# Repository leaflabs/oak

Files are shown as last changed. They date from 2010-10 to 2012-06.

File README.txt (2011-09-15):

This is the repository for the LeafLabs Oak design. This
design was created in KiCad. In order to properly view the schematics,
and to make any changes to the design, you must add the leaf hardware
and schematics libraries, available at
    http://github.com/leaflabs/hardware-lib. 

Once you have placed the libraries in a directory of your choosing,
add them as follows:

1. In EESchema (the schematic editor), click Preferences -> Library
   (or, depending on your version of KiCad, Preferences -> Libs and
   Dir). Click Add, browse to the location of leaf.lib, open it, and
   click Save Cfg. Save your project and close.

2. In CVpcb (components to modules), click Preferences ->
   Configuration. Click the Add button above the libraries window, and
   browse to the location of leaf.mod. Save the config and close.

3. In PCBnew (PCB editor), click Preferences -> Library. If leaf.mod
   is not already present, add it, save config, and close.

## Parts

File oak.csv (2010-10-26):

ref | value | footprint
BQ1 | BQ24010DRC
BUT1 | BUT
BUT2 | BUT
BUT3 | BUT
C1 | 0.1uF
C2 | 0.1uF
C3 | 0.1uF
C4 | 0.1uF
C5 | 0.1uF
C6 | 0.1uF
C7 | 0.1uF
C8 | 0.1uF
C9 | 0.1uF
C10 | 0.1uF
C11 | 0.1uF
C12 | 0.1uF
C13 | 0.1uF
C14 | 0.1uF
C15 | 0.1uF
C16 | 0.1uF
C17 | 0.1uF
C18 | 0.1uF
C19 | 0.1uF
C20 | 0.1uF
C21 | 0.1uF
C22 | 0.1uF
C23 | 0.1uF
C24 | 0.1uF
C25 | 0.1uF
C26 | 0.1uF
C27 | 0.1uF
C28 | 0.1uF
C29 | 0.47uF
C30 | 0.47uF
C31 | 1.5nF
C32 | 1.5nF
C33 | 1.5nF
C34 | 100uF
C35 | 100uF
C36 | 100uF
C37 | 10pF
C38 | 10pF
C39 | 10uF
C40 | 10uF
C41 | 10uF
C42 | 18pF
C43 | 18pF
C44 | 1nF
C45 | 1nF
C46 | 1nF
C47 | 1nF
C48 | 1nF
C49 | 1nF
C50 | 1nF
C51 | 1nF
C52 | 1nF
C53 | 1nF
C54 | 1nF
C55 | 1nF
C56 | 1nF
C57 | 1nF
C58 | 1nF
C59 | 1nF
C60 | 1nF
C61 | 1nF
C62 | 1nF
C63 | 1nF
C64 | 1nF
C65 | 1nF
C66 | 1nF
C67 | 1nF
C68 | 1uF
C69 | 47nF
C70 | 47nF
C71 | 47nF
C72 | 47nF
C73 | 47nF
C74 | 47nF
C75 | 47nF
C76 | 47nF
C77 | 47nF
C78 | 47nF
C79 | 47nF
C80 | 47nF
C81 | 47nF
C82 | 47nF
C83 | 47nF
C84 | 47nF
C85 | 47nF
C86 | 47nF
C87 | 47nF
C88 | 47nF
C89 | 47nF
C90 | 47nF
C91 | 47nF
C92 | 47nF
C93 | 47pF
C94 | 47pF
C95 | 47uF
C96 | 47uF
D1 | DIODE
D2 | DIODE
D3 | DIODE
D4 | DIODE
D5 | DIODE
D6 | DONE
D7 | Green
D8 | LED
D9 | Power
D10 | Red
IC1 | TPS75003
IC2 | XOSC
IC3 | XOSC
L1 | 5uH
L2 | 5uH
MCP1 | MCP1700T
OSC1 | 8Mhz
P1 | CONN_16X2
P2 | CONN_2
P3 | CONN_2
P4 | CONN_2
P5 | CONN_32
P6 | CONN_32
P7 | CONN_32
P8 | CONN_32
P9 | CONN_3X2
P10 | CONN_4X2
P11 | CONN_6
P12 | CONN_7X2
Q1 | MOSFET_P
Q2 | MOSFET_P
Q3 | NPN
Q4 | NPN
R1 | 1.5k
R2 | 1.5k
R3 | 10
R4 | 10k
R5 | 10k
R6 | 10k
R7 | 10k
R8 | 10k
R9 | 10k
R10 | 10k
R11 | 10k
R12 | 10k
R13 | 10k
R14 | 10k
R15 | 10k
R16 | 154k
R17 | 1k
R18 | 1k
R19 | 1k
R20 | 1k
R21 | 1k
R22 | 2.2k
R23 | 200
R24 | 200
R25 | 200
R26 | 22
R27 | 22
R28 | 365k
R29 | 36k
R30 | 390
R31 | 4.7k
R32 | 4.7k
R33 | 4.7k
R34 | 47k
R35 | 47m
R36 | 47m
R37 | 619k
R38 | 619k
S1 | SWITCH
SD1 | SD
U1 | DG4053A
U2 | MT48LC16M
U3 | STM32F103ZE
U4 | XC3S250EPQ208 | xilinx_devices-PQ208
U5 | XCF04S
USB1 | USB

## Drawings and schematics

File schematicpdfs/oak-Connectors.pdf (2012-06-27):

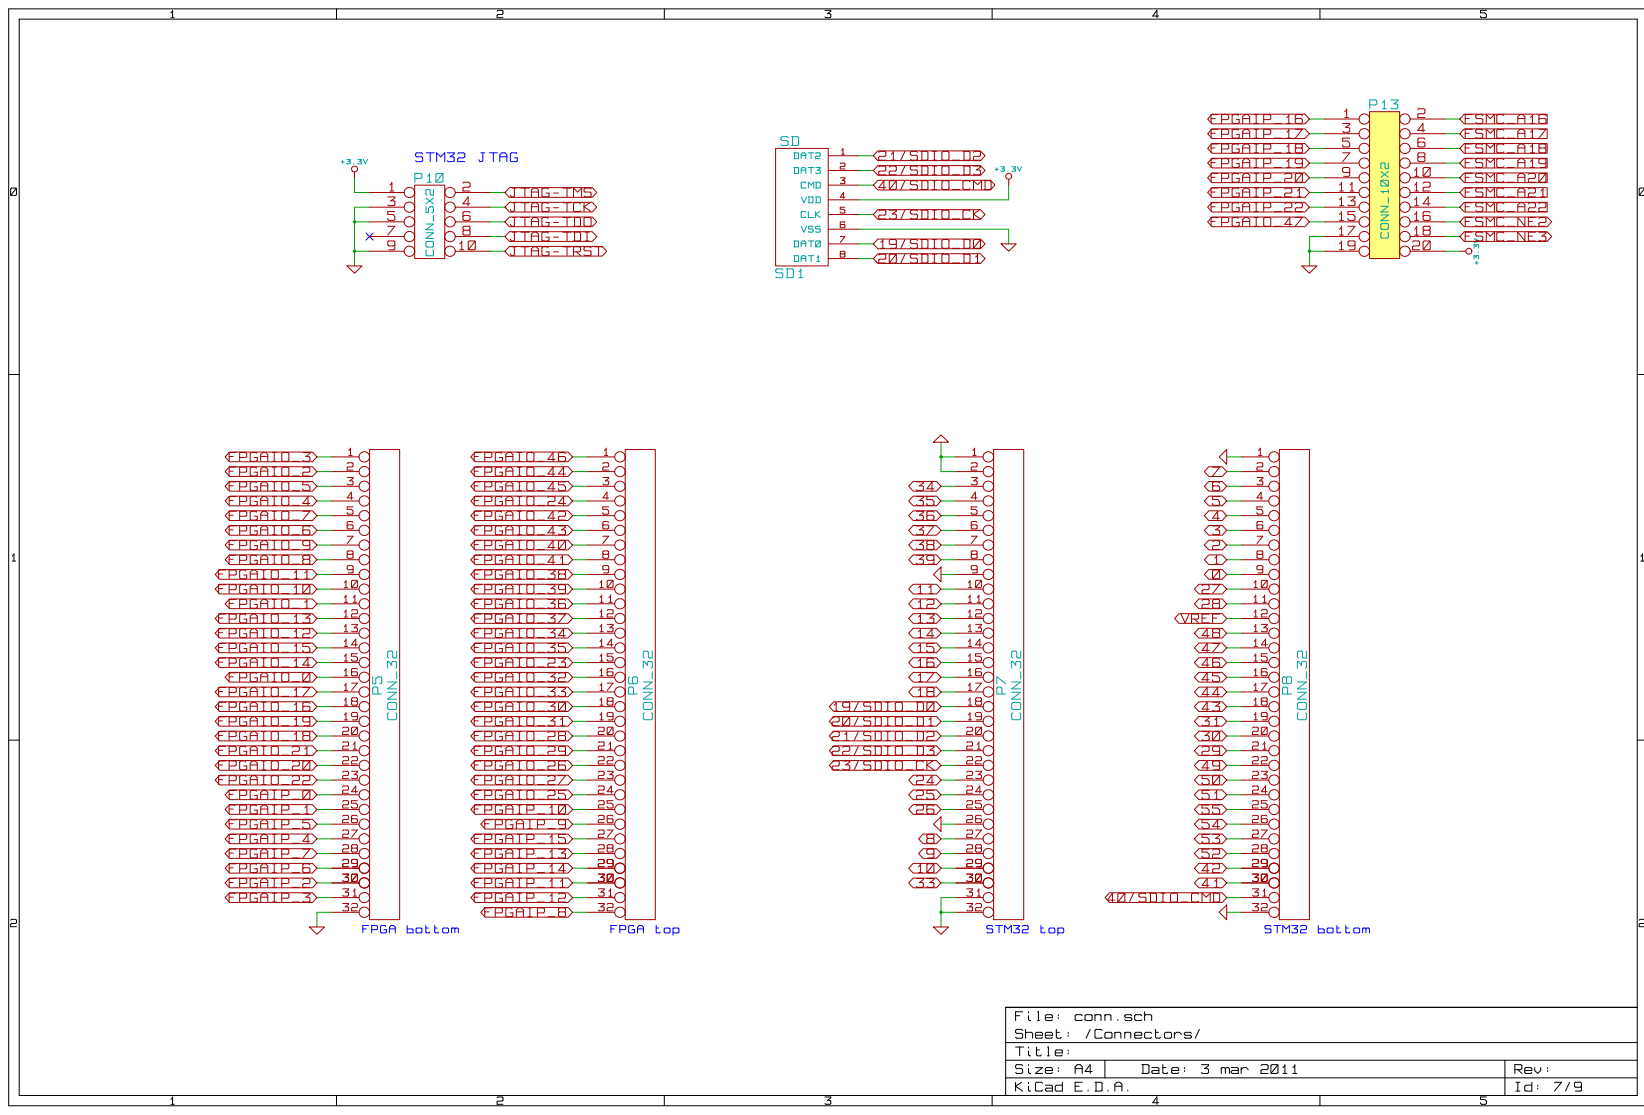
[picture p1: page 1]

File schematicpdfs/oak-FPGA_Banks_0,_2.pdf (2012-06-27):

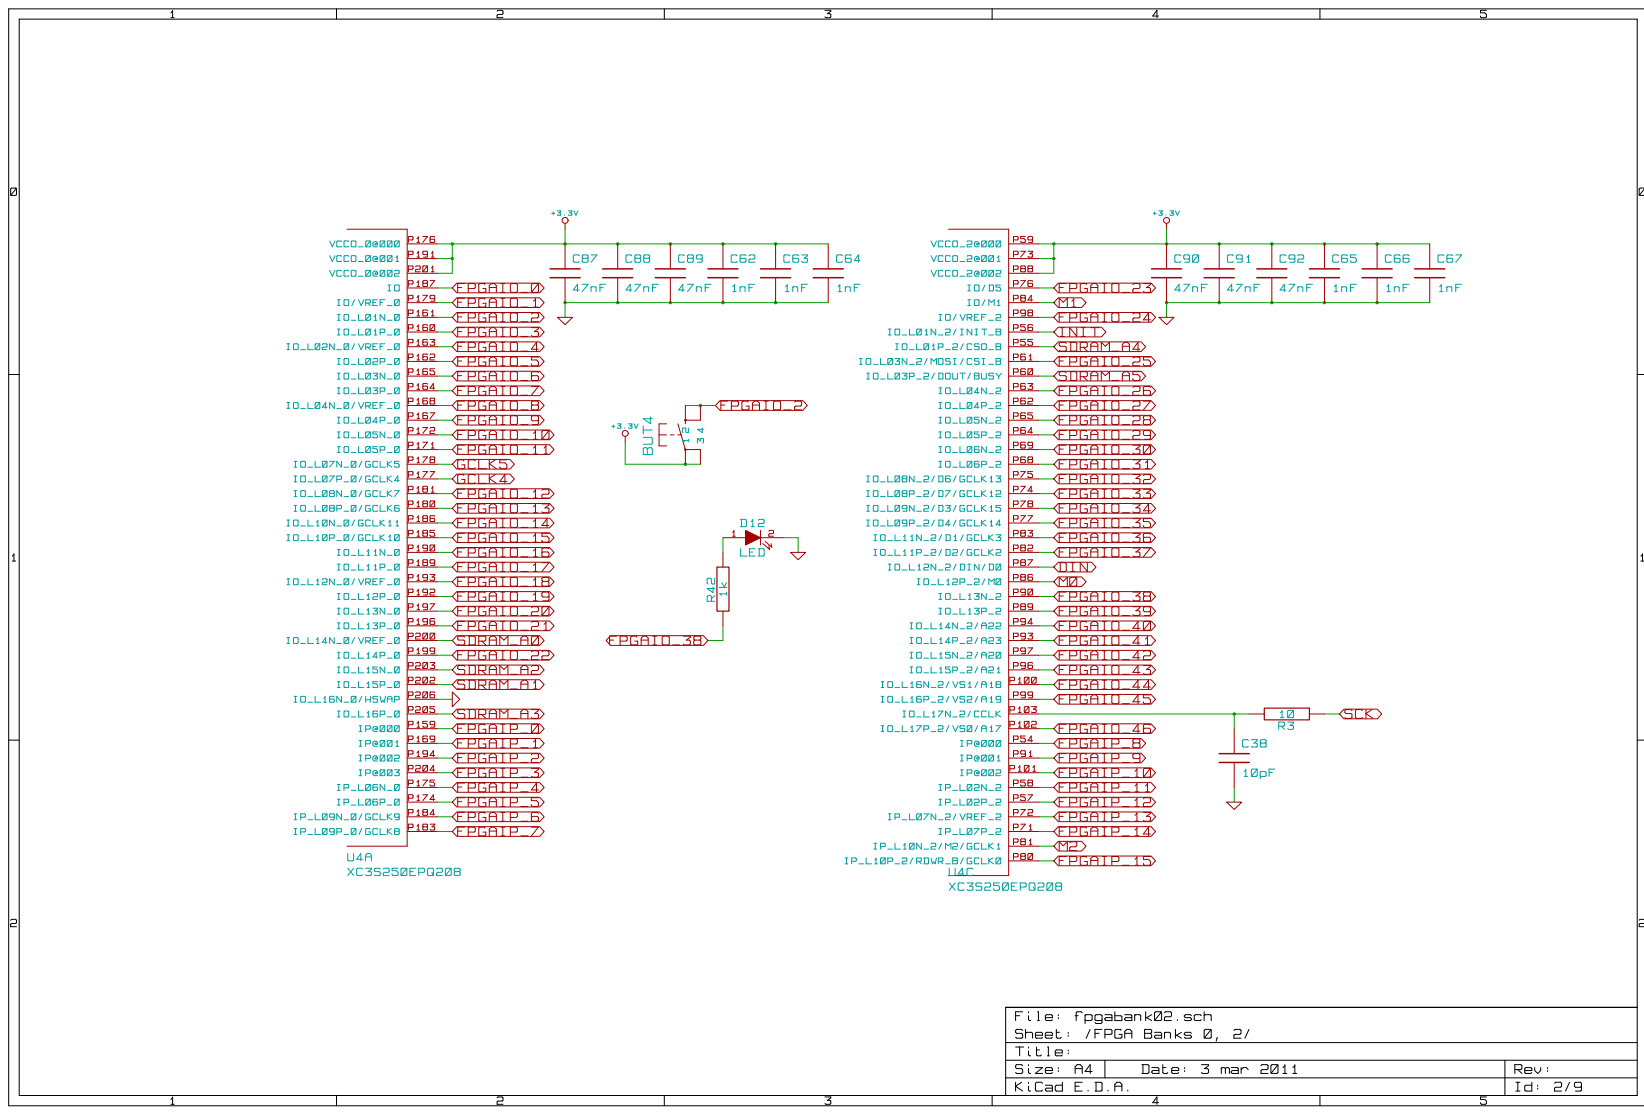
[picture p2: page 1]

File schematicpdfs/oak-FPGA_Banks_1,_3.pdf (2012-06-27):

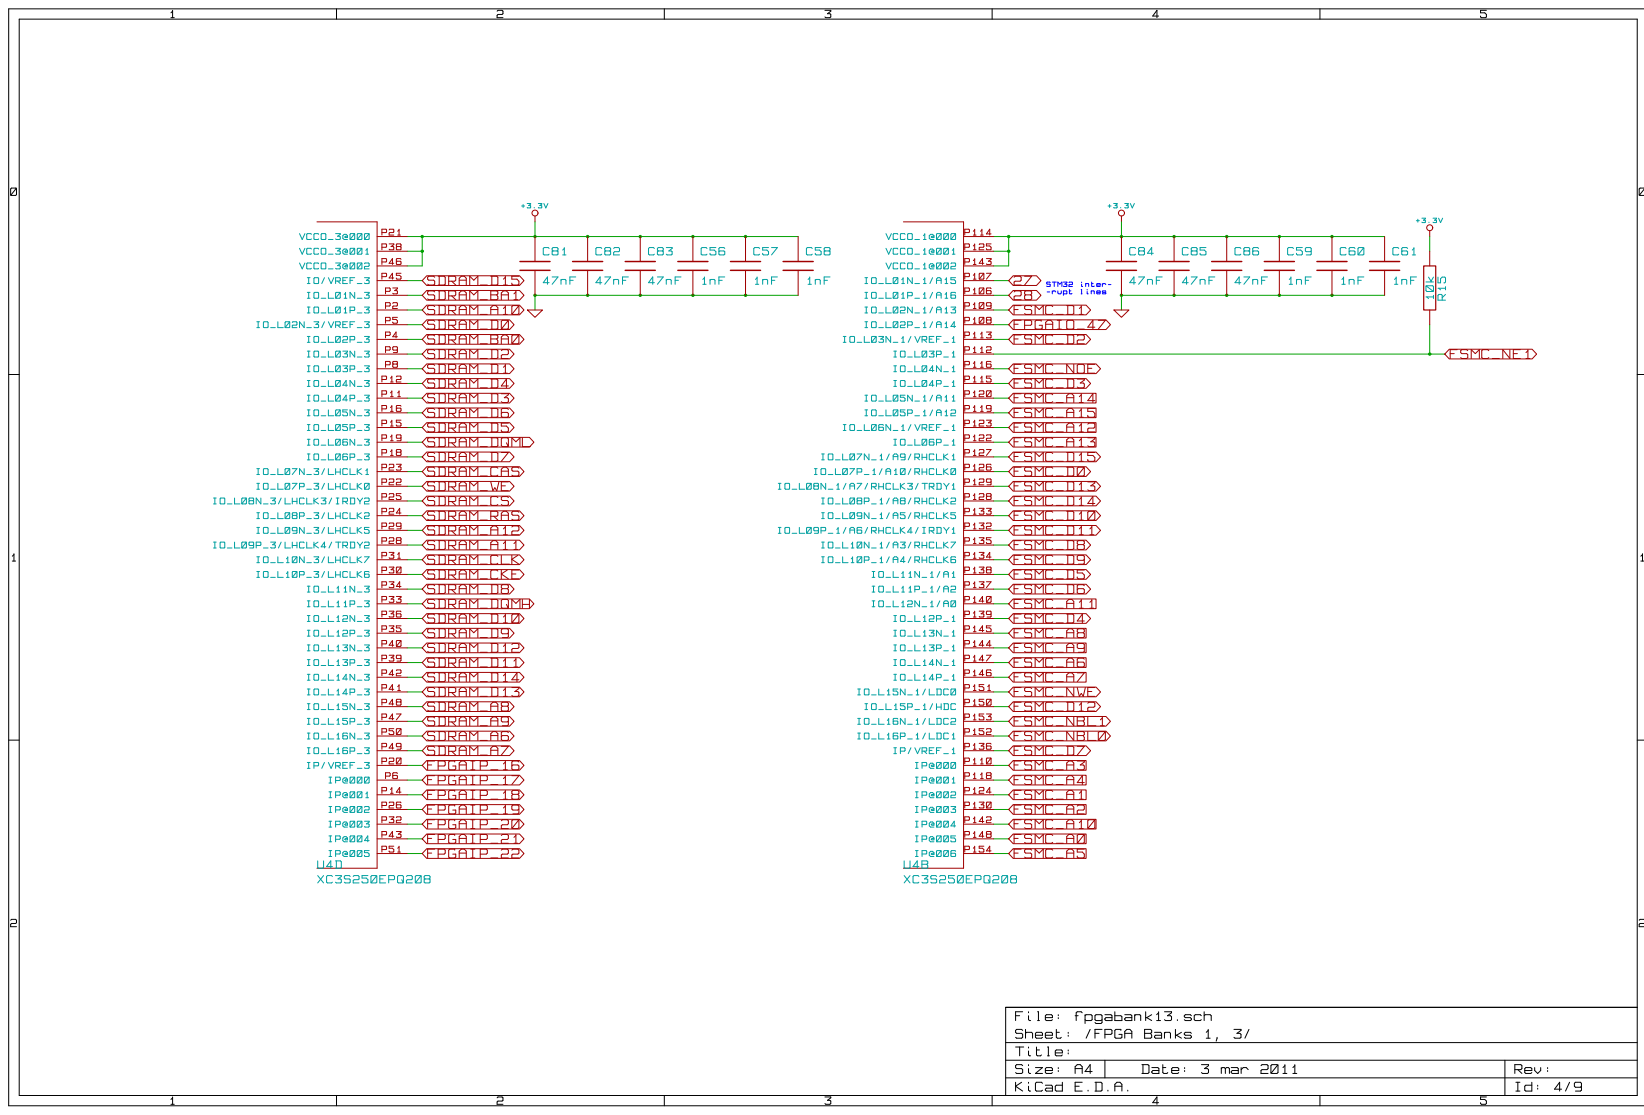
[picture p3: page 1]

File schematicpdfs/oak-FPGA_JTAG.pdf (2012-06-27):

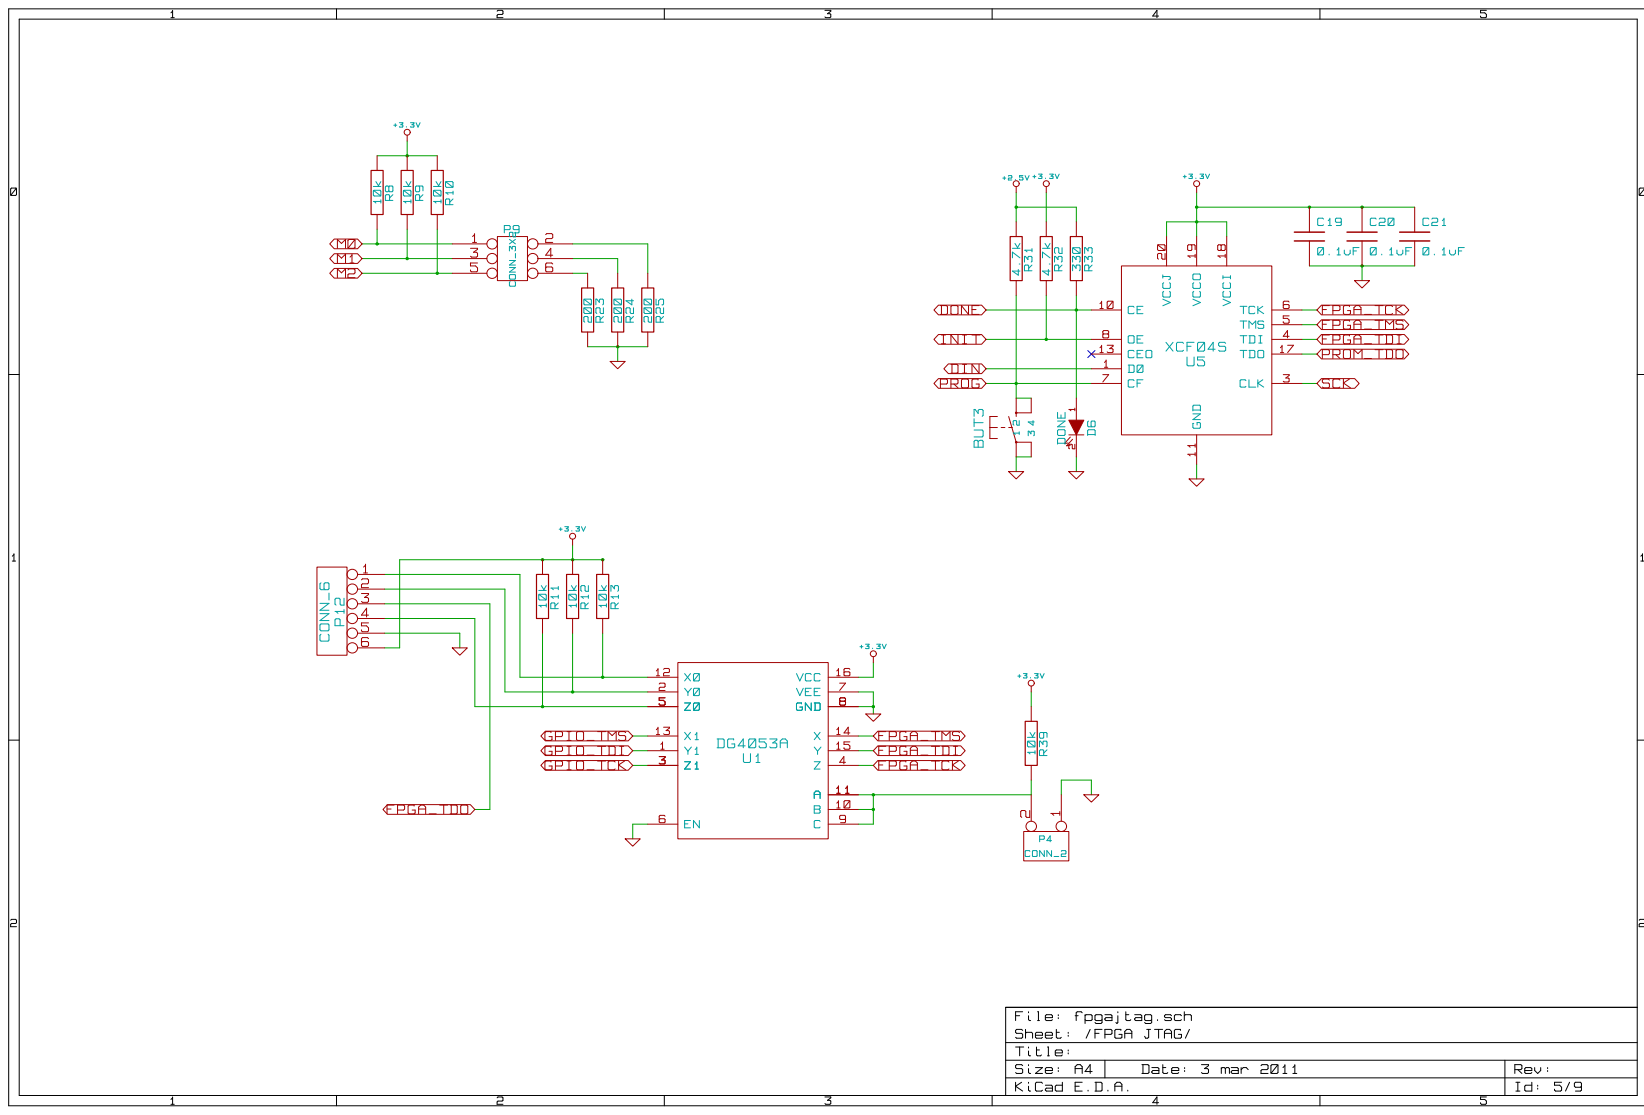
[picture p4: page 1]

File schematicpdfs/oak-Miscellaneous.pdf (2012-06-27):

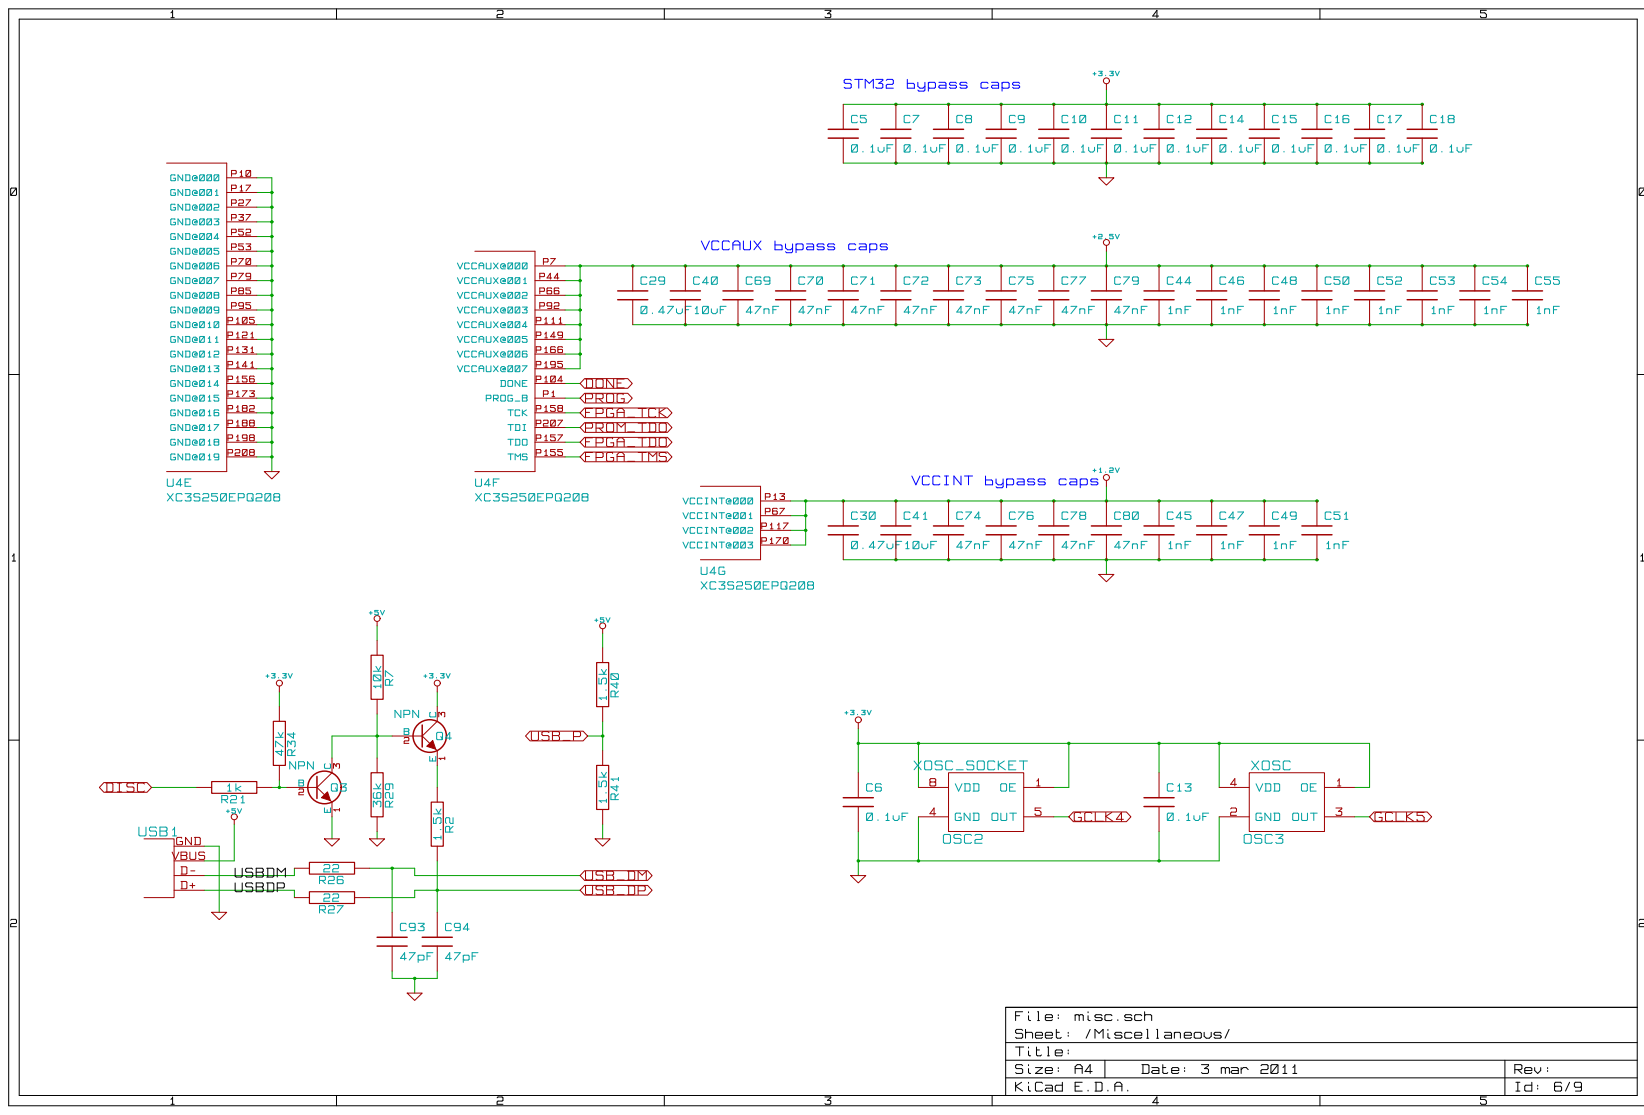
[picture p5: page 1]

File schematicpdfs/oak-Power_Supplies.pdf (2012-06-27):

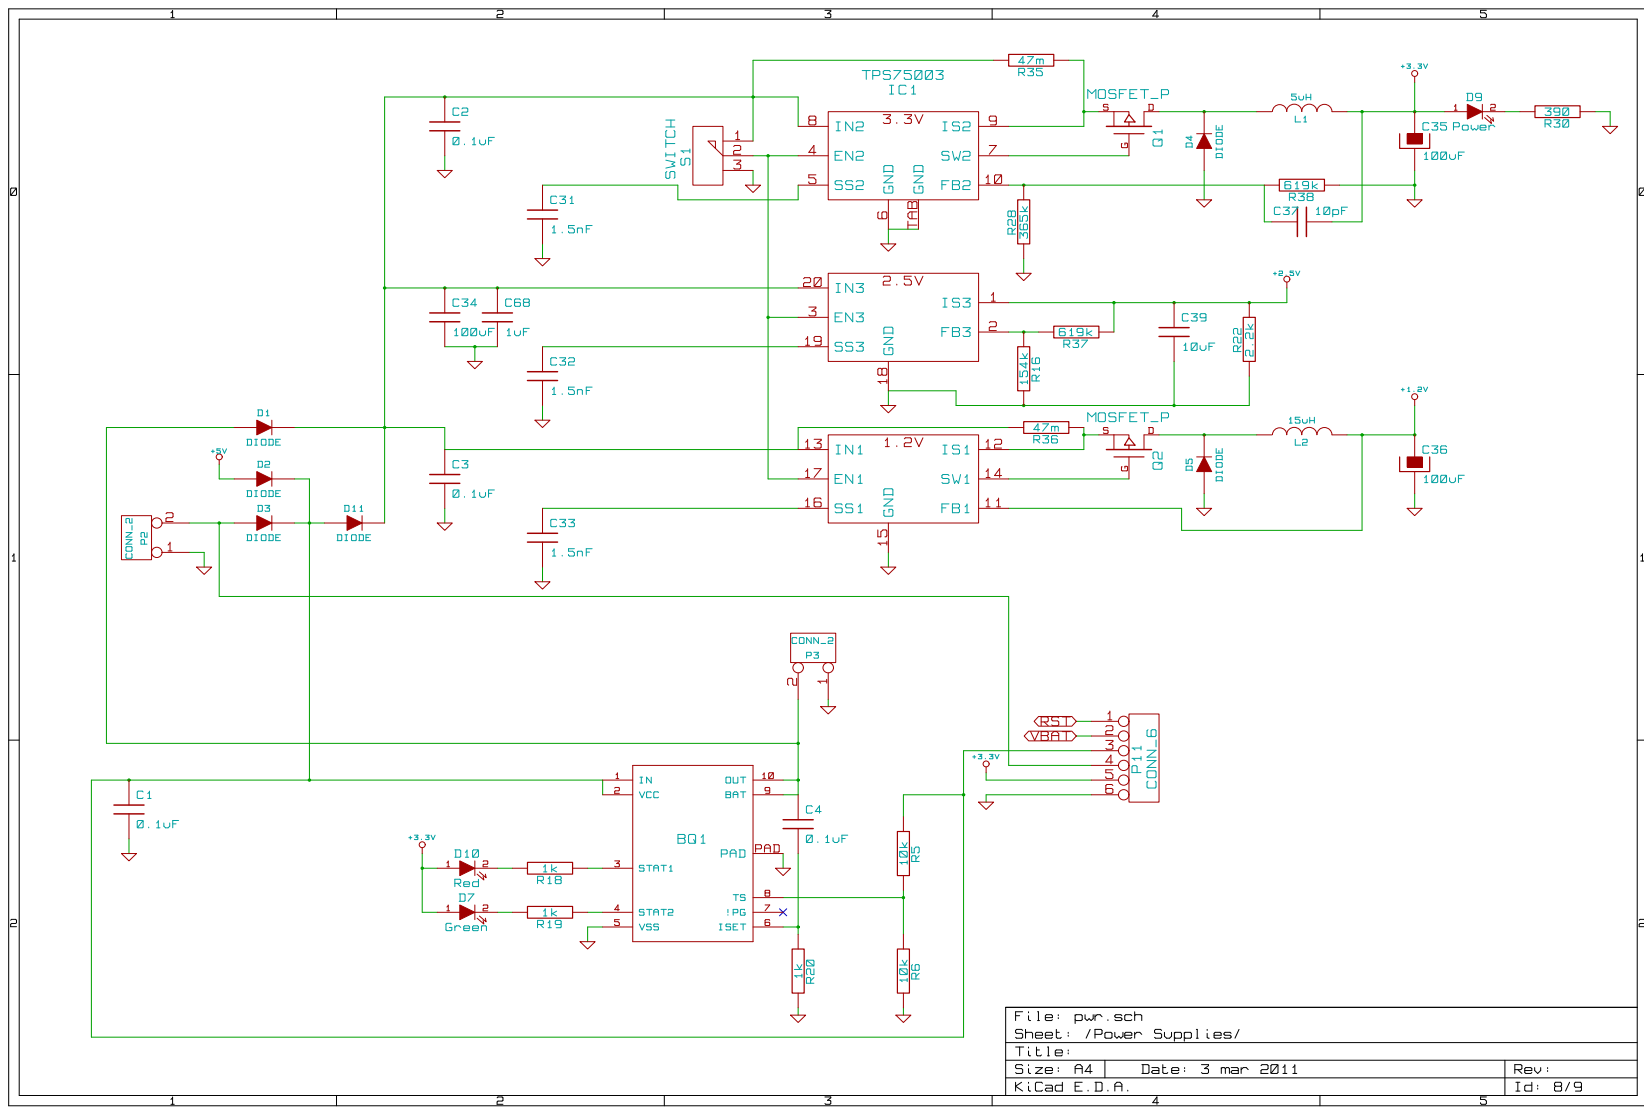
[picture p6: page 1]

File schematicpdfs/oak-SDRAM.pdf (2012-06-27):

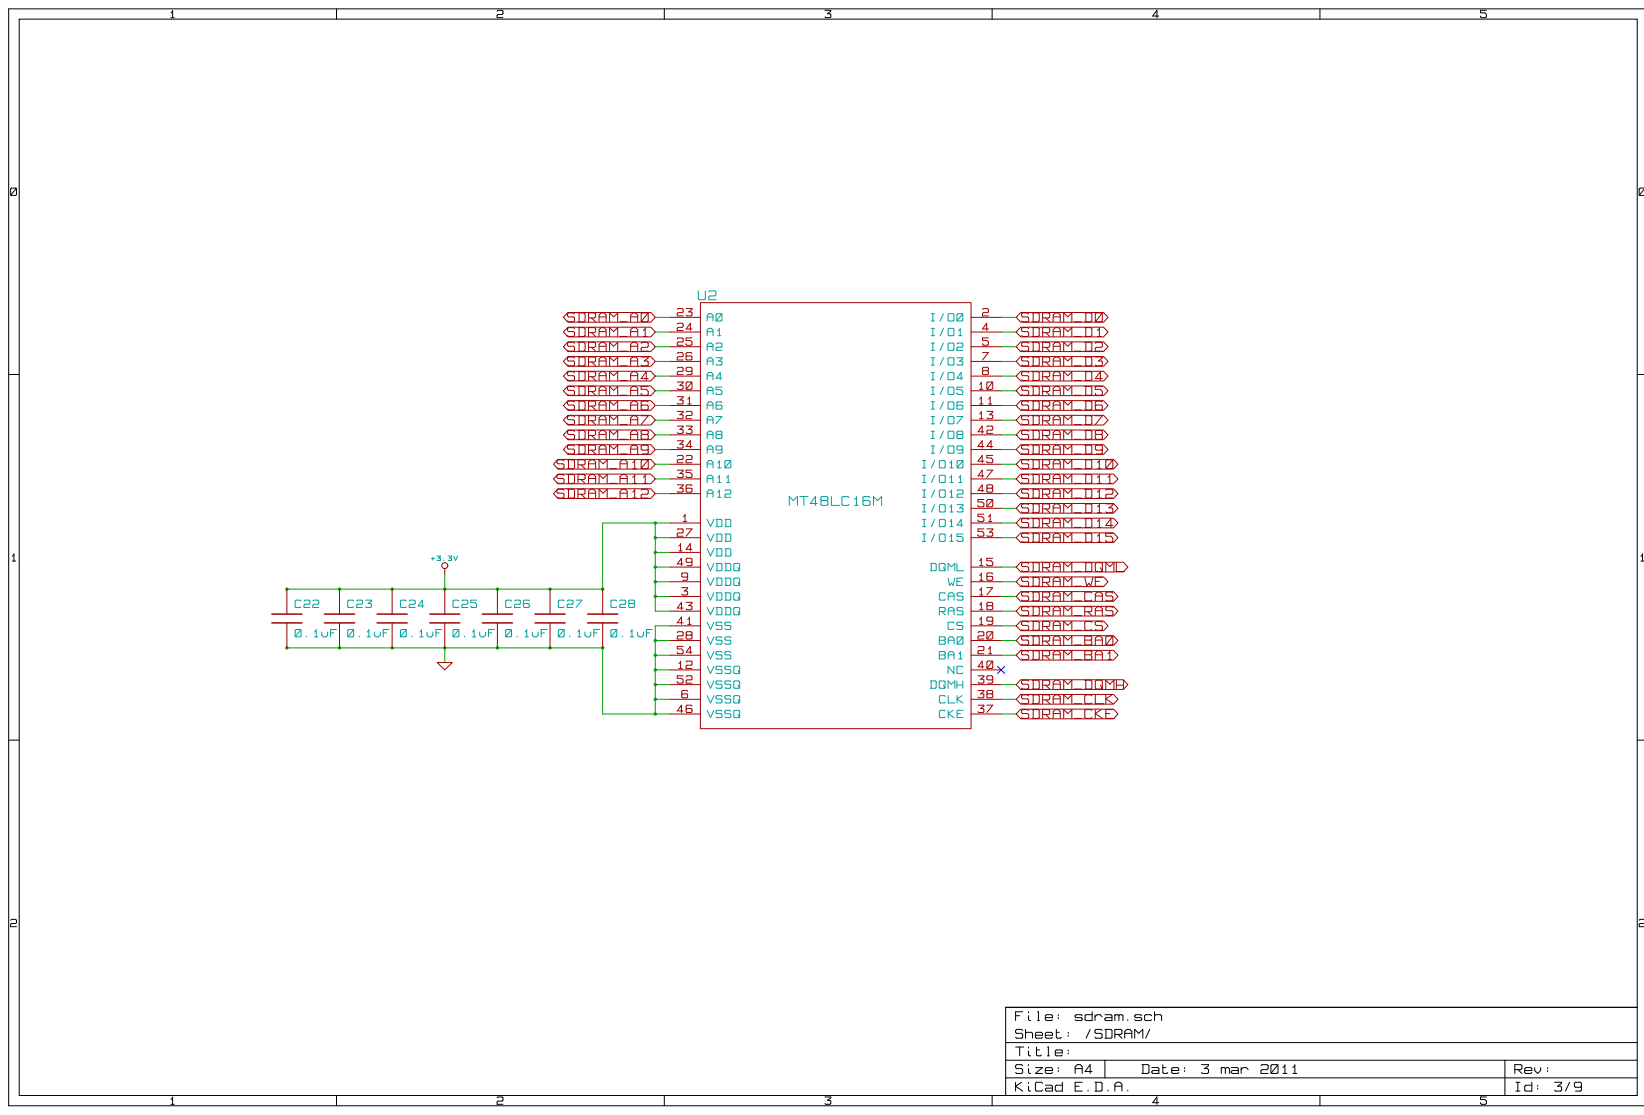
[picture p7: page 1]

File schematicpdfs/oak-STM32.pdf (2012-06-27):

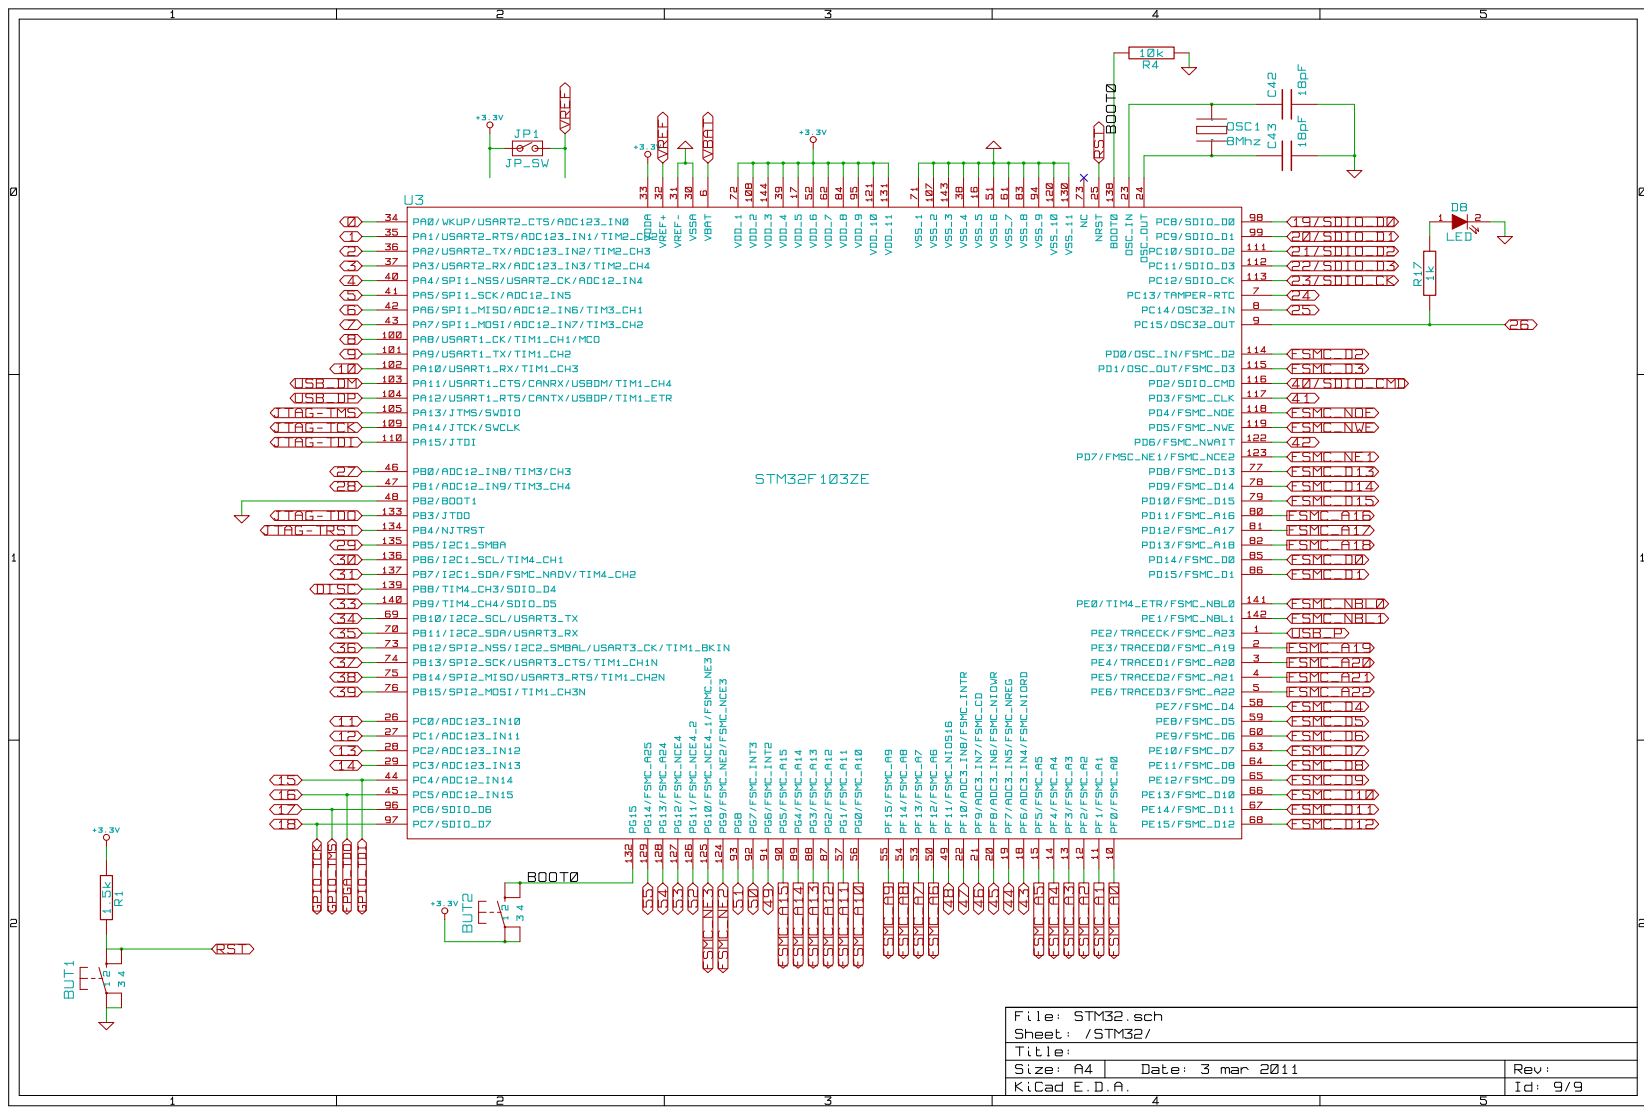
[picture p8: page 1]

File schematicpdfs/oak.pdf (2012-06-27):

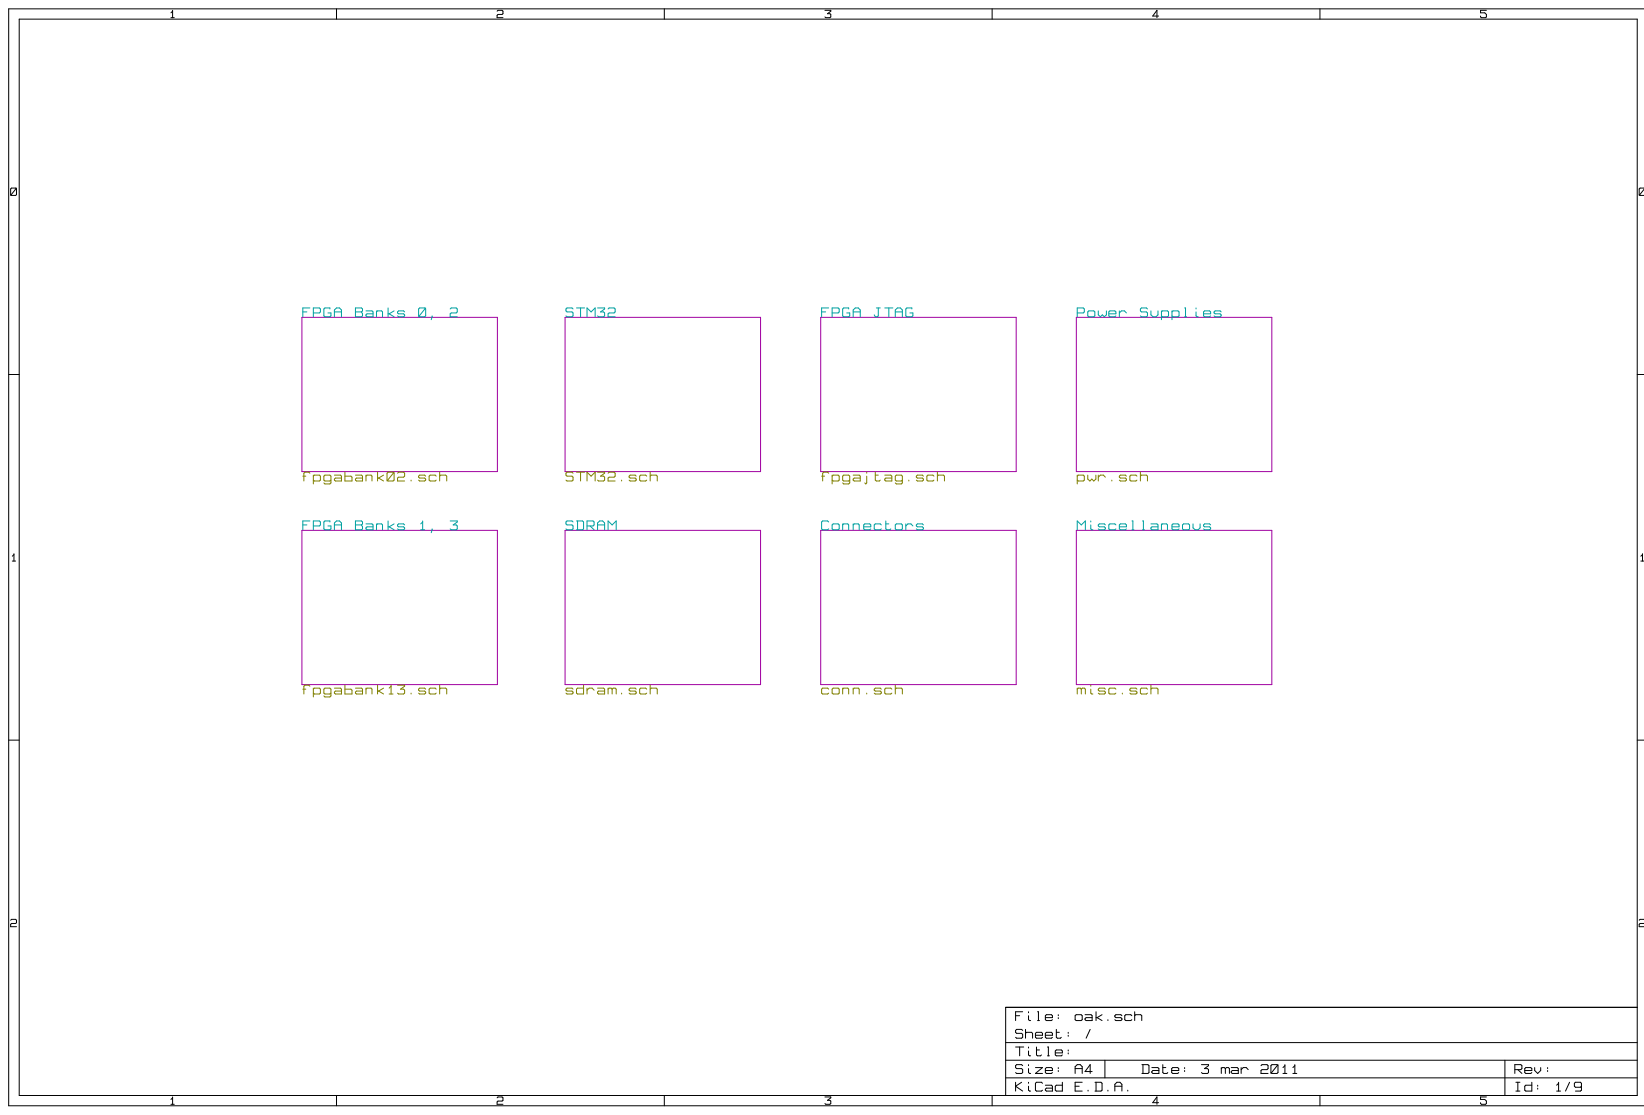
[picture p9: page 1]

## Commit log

2010-10-05 Power sheet done
    [STM32.sch, conn.sch, pwr.sch]
2010-10-05 Bypass caps
    [STM32.sch, conn.sch, pwr.sch]
2010-10-05 Jtag chain
    [fpgajtag.sch, oak.sch, prom.sch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]
2010-10-19 adding fsmc lines
    [STM32.sch, conn.sch, fpgajtag.sch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]
2010-10-20 Changed to 208 fpga
    [STM32.sch, conn.sch, fpgajtag.sch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]
2010-10-20 Added sdram
    [STM32.sch, conn.sch, fpgajtag.sch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]
2010-10-20 sdram connected
    [STM32.sch, conn.sch, fpgajtag.sch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]
2010-10-20 ready for first pass review
    [FSMCbus.sch, STM32.sch, conn.sch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]
2010-10-23 ERC checks out
    [fpgajtag.sch, misc.sch, pwr.sch]
2010-10-26 footprint bindings, BOM
    [$savepcb.brd, STM32.sch, conn.sch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]
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2010-11-08 Components partially placed, mysterious ground-vcc tie issue?
    [$savepcb.brd, STM32.sch, conn.sch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]
2010-11-08 Maybe fixing ground power tie issue
    [$savepcb.brd, STM32.sch, conn.sch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]
2010-11-08 ground-vcc tie fixed, osc socket fixed
    [STM32.sch, conn.sch, misc.sch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]
2010-11-09 33v bypass caps placed
    [$savepcb.brd]
2010-11-09 vccaux caps placed
    [$savepcb.brd]
2010-11-09 fpga power structure - halfway done
    [$savepcb.brd]
2010-11-09 fpga power structure placed
    [$savepcb.brd]
2010-11-09 components mostly placed; started routing
    [$savepcb.brd, misc.sch]
2010-11-09 might break sdram routing
    [$savepcb.brd]
2010-11-09 sdram routing quarter changed
    [$savepcb.brd, fpgabank13.sch]
2010-11-09 sdram half routed, bypass caps added
    [$savepcb.brd, fpgabank13.sch, misc.sch]
2010-11-20 Sdram routing
    [$savepcb.brd]
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2010-11-21 header P7 routed
    [oak.brd]
2010-11-22 More component placing
    [oak.brd]
2010-11-22 switching around IO on FPGA headers
    [$savepcb.brd, STM32.sch, conn.sch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]
2010-11-22 All FPGA IO switched
    [$savepcb.brd, conn.sch, oak.brd]
2010-11-23 routing routing routing
    [$savepcb.brd, oak.brd]
2010-11-23 left third-ish of board routed
    [$savepcb.brd, fpgabank02.sch, oak.brd]
2010-11-23 Bout to screw with fsmc lines
    [$savepcb.brd, fpgabank13.sch, oak.brd]
2010-11-23 More routing
    [$savepcb.brd, fpgabank13.sch, oak.brd]
2010-11-23 routing 95% finished
    [$savepcb.brd, oak.brd]
2010-12-17 fixed labels
    [$savepcb.brd, oak.brd]
2011-01-06 Library update
    [STM32.sch, conn.sch, fpgabank02.sch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]
2011-01-13 Ripped up traces, moved fpga
    [$savepcb.brd, oak.brd]
2011-01-17 bypass caps replaced
    [$savepcb.brd, oak.brd]
2011-01-19 bypass cap via drilling
    [$savepcb.brd, oak.brd]
2011-01-26 mem routing started
    [$savepcb.brd, STM32.sch, oak.brd]
2011-01-28 About to reroute some SDRAM lines
    [$savepcb.brd, oak.brd, oak.xls]
2011-01-29 sdram routed
    [$savepcb.brd, fpgabank02.sch, fpgabank13.sch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]
2011-02-03 Started routing fsmc
    [$savepcb.brd, oak.brd, oak.xls]
2011-02-08 Added schematic pdfs; contemplating fsmc reroute
    [$savepcb.brd, oak.brd]
2011-02-28 New pdf add
    [$savepcb.brd, STM32.sch, oak.brd]
2011-03-07 FPGA headers routed; wrong clearance size for inner layers
    [$savepcb.brd, STM32.sch, conn.sch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]
2011-03-07 Fixed clearance problem; routed ain lines
    [$savepcb.brd, oak.brd]
2011-03-07 Switching out STM32 schematic page
    [oak.brd]
2011-03-07 All GPIOs routed
    [$savepcb.brd, oak.brd]
2011-03-07 More signal routing
    [$savepcb.brd, oak.brd]
2011-03-08 STM32 JTAG header routed
    [$savepcb.brd, oak.brd]
2011-03-09 All STM32 signals routed
    [$savepcb.brd, oak.brd]
2011-03-11 Sigs routed
    [$savepcb.brd, oak.brd]
2011-03-17 Fixing a couple of footprints
    [$savepcb.brd, STM32.sch, conn.sch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]
2011-03-21 Routing power signals
    [$savepcb.brd, STM32.sch, conn.sch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]
2011-03-21 Ratsnest cleared, passes naive DRC
    [$savepcb.brd, oak.brd]
2011-03-23 Fixed mosfets
    [$savepcb.brd, STM32.sch, conn.sch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]
2011-03-23 Took analog regulator out of schematics
    [STM32.sch, conn.sch, fpgabank02.sch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]
2011-03-23 Added zone outlines
    [$savepcb.brd, oak.brd]
2011-03-24 Fixed clearance issue by battery charger
    [$savepcb.brd, oak.brd]
2011-04-01 Zones filled; passes DRC; ready to send to fab?
    [$savepcb.brd, oak.brd]
2011-04-15 Adding extra programming lines -- din and sck routed
    [$savepcb.brd, STM32.sch, conn.sch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]
2011-04-15 All new extra programming lines added and routed
    [STM32.sch, conn.sch, fpgabank02.sch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]
2011-05-21 Component side labels adjusted for assembly
    [$savepcb.brd, STM32.sch, conn.sch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]
2011-05-22 Copper side labels adjusted for assembly
    [$savepcb.brd, oak.brd]
2011-05-28 Switched glabels to match MN; correctness unverified
    [$savepcb.brd, STM32.sch, conn.sch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]
2011-05-28 Couple of track corrections on layout
    [STM32.sch, conn.sch, fpgabank02.sch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]
2011-05-28 Switched ADC lines on layout to be consistent with MN.
    [oak.brd]
2011-07-05 Looks ok on dfm check, passes DRC
    [$savepcb.brd, STM32.sch, conn.sch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]
2011-07-05 Top FPGA header pins re-named
    [$savepcb.brd, STM32.sch, conn.sch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]
2011-07-05 Both FPGA header pins re-named
    [$savepcb.brd, STM32.sch, conn.sch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]
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2011-07-06 Fixed Spartan3E footprint
    [oak.brd]
2011-07-08 Numbering added to silkscreen
    [$savepcb.brd, oak.brd]
2011-07-08 Connected BOOT0 line (track was broken accidentally in an earlier commit)
    [oak.brd]
2011-07-08 Zone refill for 15 mil clearance (was 8 mil)
    [oak.brd]
2011-08-06 Removed erroneous label from the copper layer
    [$savepcb.brd, oak.brd]
2011-08-13 Fixed R38 connections (was connected to ground; should have been powered)
    [$savepcb.brd, STM32.sch, conn.sch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]
2011-08-30 Added local labels to JTAG lines
    [$savepcb.brd, STM32.sch, conn.sch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]
2011-09-28 Fixed R37 error in layout.
    R37 is now connected to 3.3V instead of ground. Netlist also updated.
    [oak.brd]
2011-09-28 Added resistors on JTAG lines.
    100 Ohm current-limiting resistors (R43-R45) added on JTAG lines being input into FPGA.
    [STM32.sch, conn.sch, fpgabank02.sch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]
2011-09-29 Added current-limiting resistors to layout.
    [$savepcb.brd, oak.brd]
2011-09-29 Removed battery circuitry from schematic.
    Battery power and charging capabilities removed due to the need for a 5V VIN line, and lack of desire to add even more regulators.
    [STM32.sch, conn.sch, fpgabank02.sch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]
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2012-06-27 Switched out SDRAM footprint.
    [oak.brd]
2012-06-28 Added resistors to JTAG lines.
    [oak.brd]
2012-06-28 Fixed R38 error in layout.
    [oak.brd]
2012-06-29 Fixed diodes, ripped out battery modules.
    [oak.brd]
2012-06-29 Added barrel jack, jumper modules to layout
    [STM32.sch, conn.sch, fpgabank02.sch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]
2012-06-29 Tentatively placed new modules.
    [oak.brd]
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2012-06-29 Fixed broken power trace.
    [STM32.sch, conn.sch, fpgabank02.sch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]
2012-06-29 Rerouted last power trace.
    [oak.brd]
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
